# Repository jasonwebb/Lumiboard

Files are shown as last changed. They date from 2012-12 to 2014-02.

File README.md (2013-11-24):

## Lumiboard

Lumiboard is an open-source platform for controlling many types of LEDs. An external sensor board enables tons of fun interactivity, and an on-board Bluetooth transceiver let's you control everything via smartphone or tablet. Lumiboard can control all of these types of LEDs:

* Discrete LEDs
* High-power common-cathode RGB (or single-color) LEDs, up to 5W
* Basic LED strips
* Digitally-addressable LED arrays (such as NeoPixel-based packages)
* I2C LED pixels (like the BlinkM)

## Board features
* **ATMega328** with the Arduino Pro Mini (8 mHz @ 3.3V) bootloader flashed
* **Screw terminals** allow all board functions to be easily tapped into.
* **Six PWM pins** broken out and connected through a ULN2003, so you can sink two high-power RGB LEDs.
* **I2C interface** (SDA and SCL pins) for programmable LEDs like the BlinkM. 
* **Three potentiometer inputs** so you can control RGB colors directly, or connect other sensors as analog inputs.
* **External sensor board** containing a temperature sensor, ambient light sensor and sound sensor.
* **Bluetooth transceiver** accessible via SoftwareSerial, so you can easily control your LEDs remotely using your smartphone or tablet.
* **FTDI interface (3.3V)** so you can re-program the board at any time manually.

## More information
* Author website: http://jason-webb.info
* All my blog posts about this project: http://jason-webb.info/tag/lumiboard/
* Wiki: http://jason-webb.info/wiki/index.php?title=Lumiboard

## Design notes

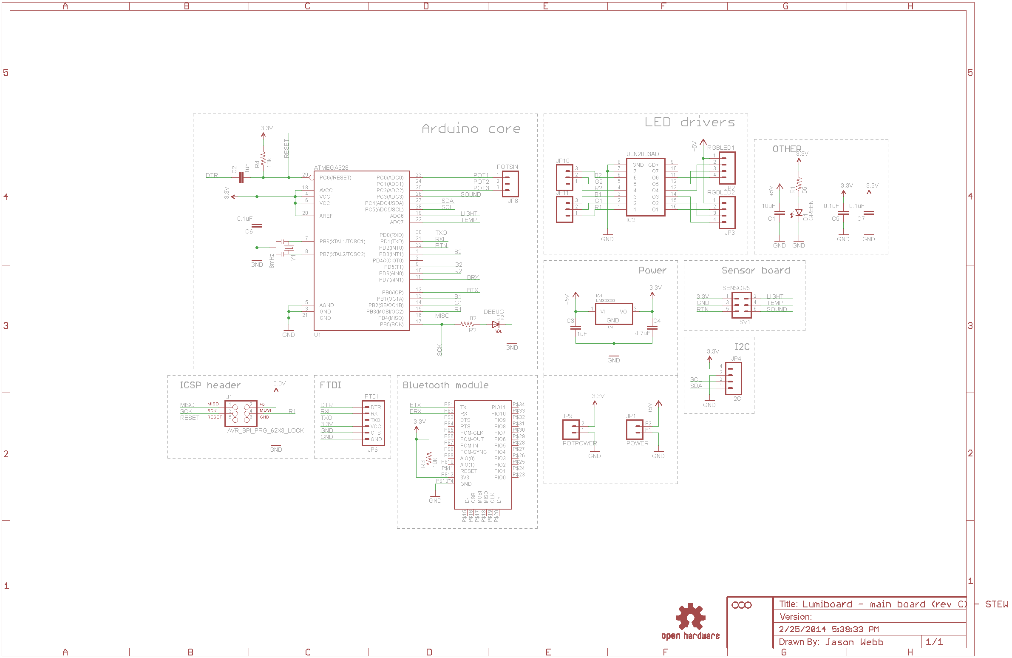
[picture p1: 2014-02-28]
Eagle files/Main board (rev C)/Lumiboard - main board (rev C) schematic.png

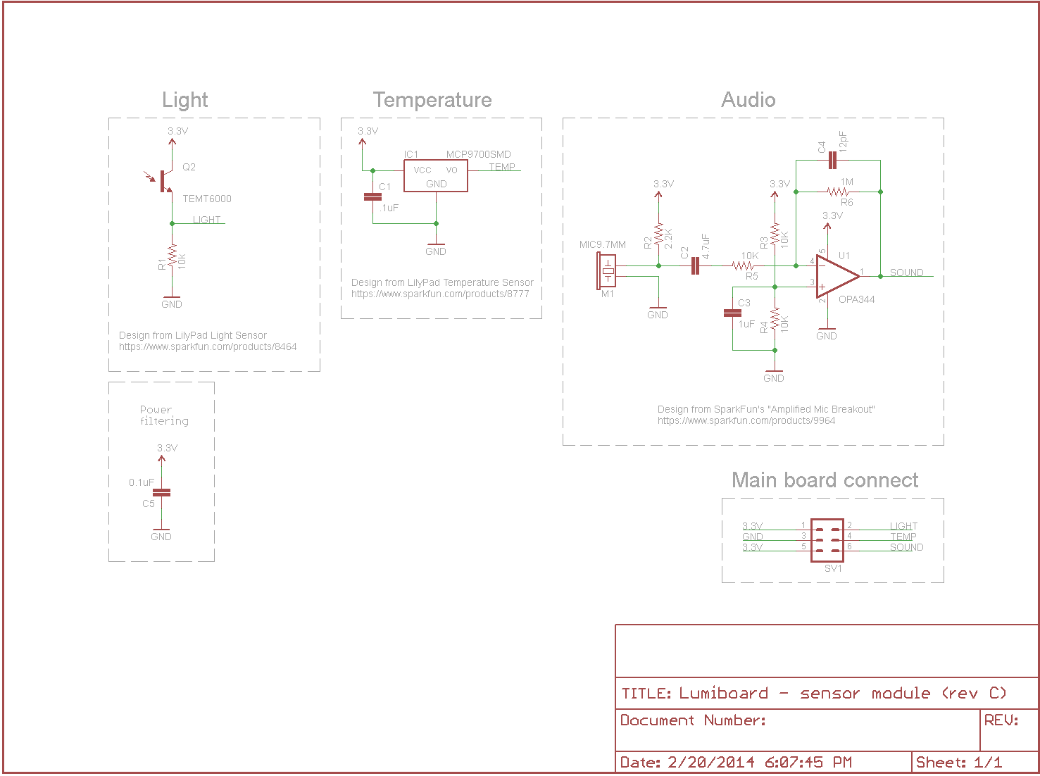
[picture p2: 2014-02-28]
Eagle files/Sensor module (rev C)/Lumiboard - sensor module (rev C) schematic.png

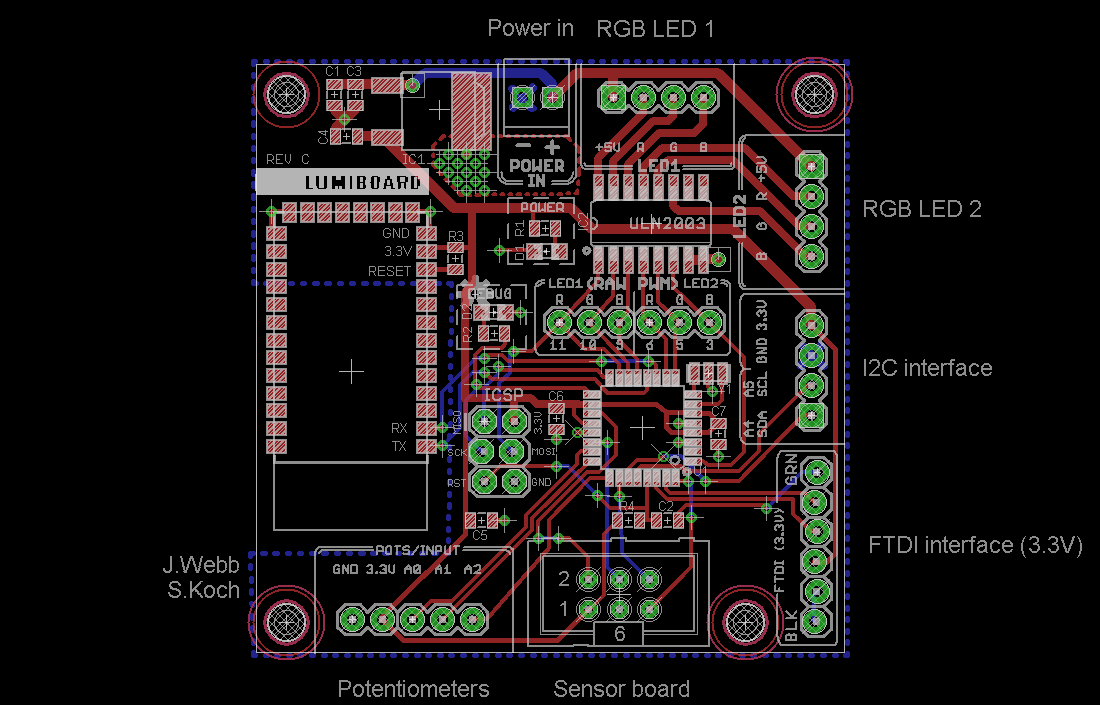
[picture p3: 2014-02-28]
Eagle files/Main board (rev C)/Lumiboard - main board (rev C) PCB.png

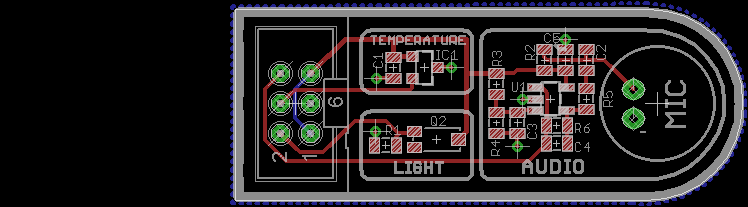
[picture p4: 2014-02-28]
Eagle files/Sensor module (rev C)/Lumiboard - sensor module (rev C) PCB.png

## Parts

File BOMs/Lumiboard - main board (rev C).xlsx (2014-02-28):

ID | Value | Package | Cost | Cost @ 50 | Cost @ 100 | Part number | Source
C1 | 10uF | 0805 | $0.20 | $0.1360 | $0.0693 | 445-7660-1-ND | http://www.digikey.com/product-detail/en/C2012X5R1A106K125AB/445-7660-1-ND/2733732
C2 | 1uF | 0805 | $0.10 | $0.0386 | $0.0327 | 1276-1066-1-ND | http://www.digikey.com/product-detail/en/CL21B105KAFNNNE/1276-1066-1-ND/3889152
C3 | 1uF | 0805 | $0.10 | $0.0386 | $0.0327 | 1276-1066-1-ND | http://www.digikey.com/product-detail/en/CL21B105KAFNNNE/1276-1066-1-ND/3889152
C4 | 4.7uF | 0805 | $0.14 | $0.0552 | $0.0456 | 1276-1065-1-ND | http://www.digikey.com/product-detail/en/CL21A475KOFNNNE/1276-1065-1-ND/3889151
C5 | 0.1uF | 0805 | $0.10 | $0.0240 | $0.0204 | 1276-1099-1-ND | http://www.digikey.com/product-detail/en/CL21B104KACNNNC/1276-1099-1-ND/3889185
C6 | 0.1uF | 0805 | $0.10 | $0.0240 | $0.0204 | 1276-1099-1-ND | http://www.digikey.com/product-detail/en/CL21B104KACNNNC/1276-1099-1-ND/3889185
C7 | 0.1uF | 0805 | $0.10 | $0.0240 | $0.0204 | 1276-1099-1-ND | http://www.digikey.com/product-detail/en/CL21B104KACNNNC/1276-1099-1-ND/3889185
D1 | Power LED (green) | 0805 | $0.08 | $0.0680 | $0.0546 | 475-1410-1-ND | http://www.digikey.com/product-detail/en/LG%20R971-KN-1-0-20-R18/475-1410-1-ND/1802598
D2 | Debug LED (red) | 0805 | $0.41 | $0.2890 | $0.1901 | 160-1579-1-ND | http://www.digikey.com/product-detail/en/LTST-C170TBKT/160-1579-1-ND/564889
IC1 | LM39300 | D-PAK | $1.57 | $1.2528 | $1.0962 | 497-6874-1-ND | http://www.digikey.com/product-detail/en/LD39300DT33-R/497-6874-1-ND/1880253
IC2 | ULN2003AD | 16-SOIC | $0.59 | $0.4332 | $0.3708 | 296-1368-1-ND | http://www.digikey.com/product-detail/en/ULN2003ADR/296-1368-1-ND/404968?cur=USD
J1 | 2x3 ICSP header
JP1 | Main power input | 2-pin .100" pitch terminal block | $0.54 | $0.4080 | $0.3910 | ED10561-ND | http://www.digikey.com/product-detail/en/OSTVN02A150/ED10561-ND/1588862
JP2 | RGB LED 1 output | 4-pin .100" pitch terminal block | $0.99 | $0.7820 | $0.7480 | ED10563-ND | http://www.digikey.com/product-detail/en/OSTVN04A150/ED10563-ND/1588864
Jp3 | RGB LED 2 output | 4-pin .100" pitch terminal block | $0.99 | $0.7820 | $0.7480 | ED10563-ND | http://www.digikey.com/product-detail/en/OSTVN04A150/ED10563-ND/1588864
JP4 | I2C output | 4-pin .100" pitch terminal block | $0.99 | $0.7820 | $0.7480 | ED10563-ND | http://www.digikey.com/product-detail/en/OSTVN04A150/ED10563-ND/1588864
JP6 | FTDI header
JP8 | Pot input | 5-pin .100" pitch terminal block | $1.22 | $0.9660 | $0.9240 | ED10564-ND | http://www.digikey.com/product-search/en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
JP9 | Pot power | (part of above jumper)
JP10 | PWM pins 1 | 1x6 male header | $0.21 | $0.1484 | $0.1378 | 952-2270-ND | http://www.digikey.com/product-detail/en/M20-9990646/952-2270-ND/3728234
JP11 | PWM pins 2 | (part of above jumper)
R1 | 56 ohms | 0805 | $0.10 | $0.0196 | $0.0149 | P56ACT-ND | http://www.digikey.com/product-detail/en/ERJ-6GEYJ560V/P56ACT-ND/42928
R2 | 82 ohms | 0805 | $0.10 | $0.0196 | $0.0149 | P82ACT-ND | http://www.digikey.com/product-detail/en/ERJ-6GEYJ820V/P82ACT-ND/42830
R3 | 10k | 0805 | $0.10 | $0.0196 | $0.0149 | P10KACT-ND | http://www.digikey.com/product-detail/en/ERJ-6GEYJ103V/P10KACT-ND/43118
R4 | 10k | 0805 | $0.10 | $0.0196 | $0.0149 | P10KACT-ND | http://www.digikey.com/product-detail/en/ERJ-6GEYJ103V/P10KACT-ND/43118
SV1 | Sensor connect | 2x3 shrouded header | $0.74 | $0.5542 | $0.5311 | 609-2845-ND | http://www.digikey.com/product-detail/en/75869-131LF/609-2845-ND/1302569?cur=USD
U1 | ATMEGA328P-AU-ND | 32-TQFP | $3.12 | $1.9868 | $1.7738 | ATMEGA328P-AU-ND | http://www.digikey.com/product-detail/en/ATMEGA328P-AU/ATMEGA328P-AU-ND/1832260
U2 | HM-10 BLE4 module | Breakout board | $6.87 | $6.25 | $6.25 | 1292002 | http://www.fasttech.com/product/1292002-ti-cc2540-bluetooth-4-0-ble-2540-transparent
Y1 | 8 mHz resonator | 3-SMD | $0.46 | $0.3456 | $0.3074 | 490-1195-1-ND | http://www.digikey.com/product-detail/en/CSTCE8M00G55-R0/490-1195-1-ND/584632?cur=USD
 |  | Parts total (without BT) | $13.15 | $9.22 | $8.32
 |  | Parts total (with BT) | $20.02 | $15.47 | $14.57

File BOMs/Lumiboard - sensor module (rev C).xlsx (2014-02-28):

ID | Value | Package | Cost | Cost @ 50 | Cost @ 100 | Part number | Source
C1 | 0.1uF | 0805 | $0.10 | $0.0240 | $0.0204 | 1276-1099-1-ND | http://www.digikey.com/product-detail/en/CL21B104KACNNNC/1276-1099-1-ND/3889185
C2 | 4.7uF | 0805 | $0.14 | $0.0552 | $0.0456 | 1276-1065-1-ND | http://www.digikey.com/product-detail/en/CL21A475KOFNNNE/1276-1065-1-ND/3889151
C3 | 1uF | 0805 | $0.10 | $0.0386 | $0.0327 | 1276-1029-1-ND | http://www.digikey.com/product-detail/en/CL21B105KBFNNNE/1276-1029-1-ND/3889115
C4 | 12pF | 0805 | $0.10 | $0.0260 | $0.0220 | 1276-1120-1-ND | http://www.digikey.com/product-detail/en/CL21C120JBANNNC/1276-1120-1-ND/3889206
C5 | 0.1uF | 0805 | $0.10 | $0.0240 | $0.0204 | 1276-1099-1-ND | http://www.digikey.com/product-detail/en/CL21B104KACNNNC/1276-1099-1-ND/3889185
IC1 | MCP9700 | SOT23-3 | $0.30 | $0.2100 | $0.1900 | MCP9700T-E/TTCT-ND | http://www.digikey.com/product-detail/en/MCP9700T-E%2FTT/MCP9700T-E%2FTTCT-ND/1212545
M1 | Electret mic | 9.7mm | $0.96 | $0.7460 | $0.5693 | 102-1721-ND | http://www.digikey.com/product-detail/en/CMA-4544PF-W/102-1721-ND/1869981?cur=USD
Q2 | TEMPT6000 ambient light sensor | 1206 | $1.27 | $1.0052 | $0.9045 | 751-1055-1-ND | http://www.digikey.com/product-detail/en/TEMT6000X01/751-1055-1-ND/1681410?cur=USD
R1 | 10k | 0805 | $0.10 | $0.0196 | $0.0149 | P10KACT-ND | http://www.digikey.com/product-detail/en/ERJ-6GEYJ103V/P10KACT-ND/43118
R2 | 2.2k | 0805 | $0.10 | $0.0196 | $0.0149 | P2.2KACT-ND | http://www.digikey.com/product-detail/en/ERJ-6GEYJ222V/P2.2KACT-ND/93214
R3 | 10k | 0805 | $0.10 | $0.0196 | $0.0149 | P10KACT-ND | http://www.digikey.com/product-detail/en/ERJ-6GEYJ103V/P10KACT-ND/43118
R4 | 10k | 0805 | $0.10 | $0.0196 | $0.0149 | P10KACT-ND | http://www.digikey.com/product-detail/en/ERJ-6GEYJ103V/P10KACT-ND/43118
R5 | 10k | 0805 | $0.10 | $0.0196 | $0.0149 | P10KACT-ND | http://www.digikey.com/product-detail/en/ERJ-6GEYJ103V/P10KACT-ND/43118
R6 | 1M | 0805 | $0.10 | $0.0288 | $0.0219 | P1.00MCCT-ND | http://www.digikey.com/product-detail/en/ERJ-6ENF1004V/P1.00MCCT-ND/119836
SV1 | Main board connect | 2x3 shrouded header | $0.74 | $0.5542 | $0.5311 | 609-2845-ND | http://www.digikey.com/product-detail/en/75869-131LF/609-2845-ND/1302569?cur=USD
U1 | OPA344 | SOT23-5 | $1.66 | $1.3416 | $1.2046 | OPA344NACT-ND | http://www.digikey.com/product-detail/en/OPA344NA%2F250/OPA344NACT-ND/362263
 |  | Unit cost | $6.07 | $4.15 | $3.64

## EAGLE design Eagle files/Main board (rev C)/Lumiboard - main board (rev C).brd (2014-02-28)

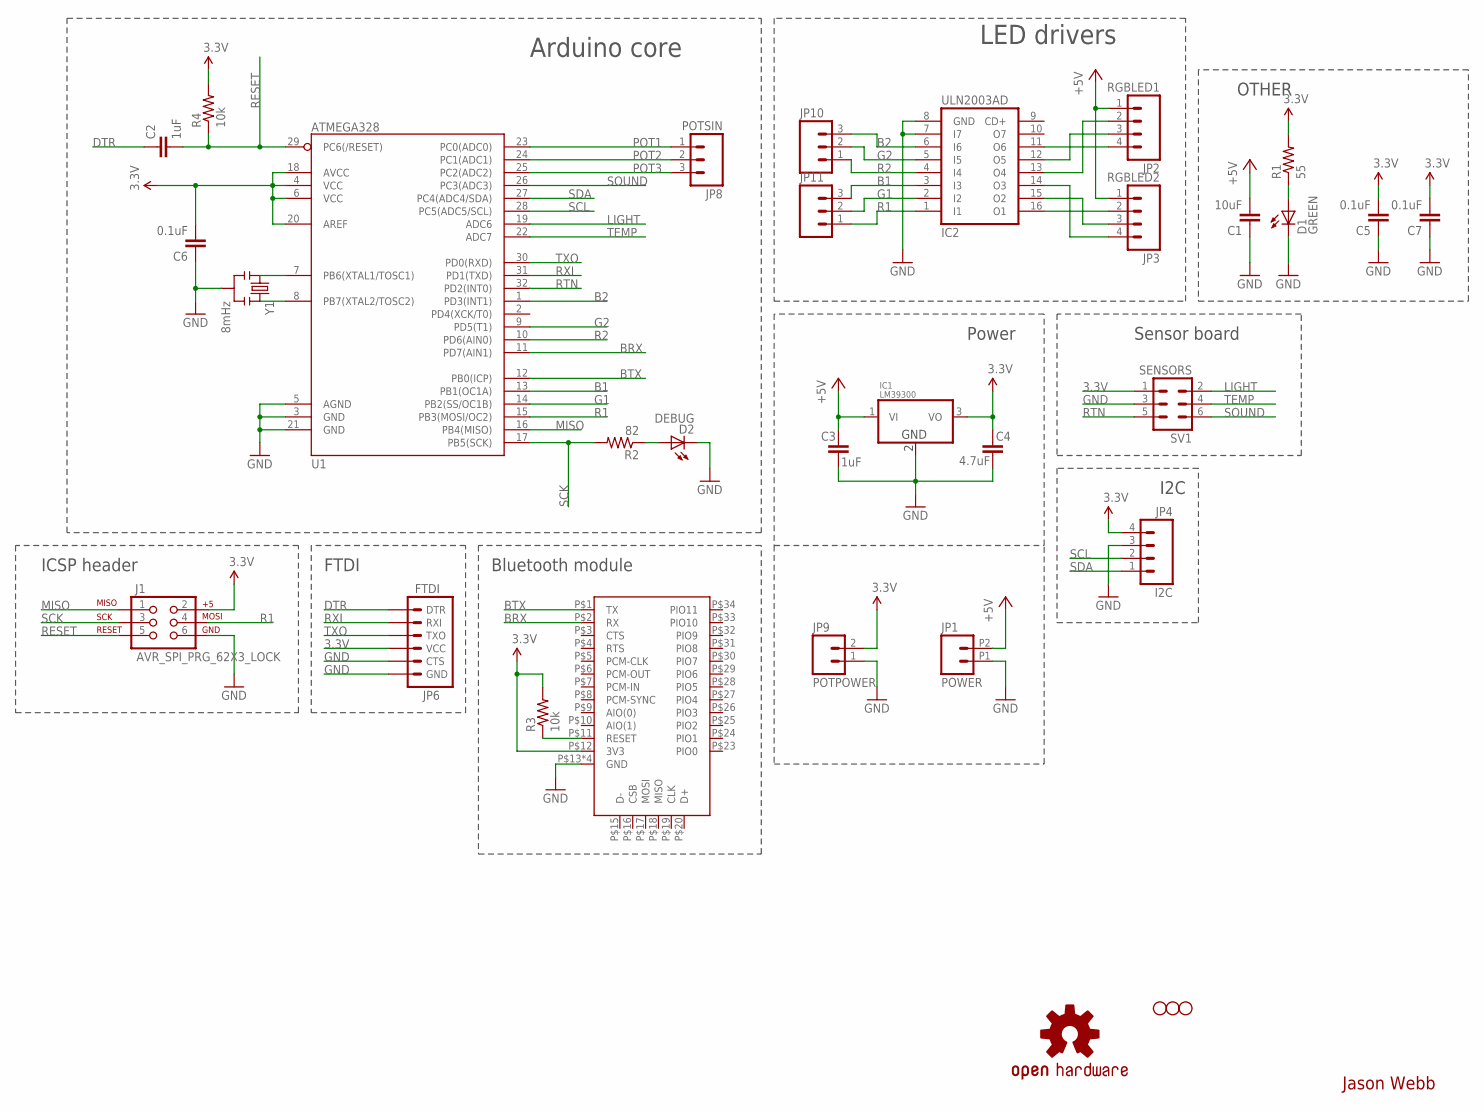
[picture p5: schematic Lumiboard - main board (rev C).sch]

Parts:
C1: 10uF; 0805
C2, C3: 1uF; 0805
C4: 4.7uF; 0805
C5, C6, C7: 0.1uF; 0805
D1: GREEN; CHIPLED_0805
D2: DEBUG; CHIPLED_0805
H1, H2, H3: STAND-OFFTIGHT; STAND-OFF-TIGHT
IC1: LM39300; DPAK
IC2: ULN2003AD; SO16
J1: AVR_SPI_PRG_62X3_LOCK; 2X3_LOCK
JP1: POWER; 1X02_2.54_SCREWTERM
JP2: RGBLED1; 1X04
JP3: RGBLED2; 1X04
JP4: I2C; 1X04
JP6: FTDI; 1X06_LOCK
JP8: POTSIN; 1X03
JP9: POTPOWER; 1X02
JP10, JP11: M03PTH; 1X03
LOGO1: OSHW-LOGOS; OSHW-LOGO-S
R1: 55; 0805
R2: 82; 0805
R3, R4: 10k; 0805
SV1: SENSORS; ML6
U1: ATMEGA328; TQFP32-08
U2: DX_BT_MODULE; DXBLUETOOTHMODULE
Y1: 8mHz; RESONATOR-SMD

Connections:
3.3V: C4.2, C5.2, C6.2, C7.2, IC1.3 (VO), J1.2, JP4.4, JP6.4 (VCC), JP9.2, R1.2, R3.2, R4.2, SV1.1, U1.4 (VCC), U1.6 (VCC), U1.18 (AVCC), U1.20 (AREF), U2.P$12 (3V3)
+5V: C1.2, C3.2, IC1.1 (VI), JP1.P2 (2), JP2.1, JP3.1
B1: IC2.3 (I3), JP11.3, U1.13 (PB1(OC1A))
B2: IC2.6 (I6), JP10.3, U1.1 (PD3(INT1))
BRX: U1.11 (PD7(AIN1)), U2.P$2 (RX)
BTRESET: R3.1, U2.P$11 (RESET)
BTX: U1.12 (PB0(ICP)), U2.P$1 (TX)
DTR: C2.1, JP6.1 (DTR)
G1: IC2.2 (I2), JP11.2, U1.14 (PB2(SS/OC1B))
G2: IC2.5 (I5), JP10.2, U1.9 (PD5(T1))
GND: C1.1, C3.1, C4.1, C5.1, C6.1, C7.1, D1.C, D2.C, IC1.2 (GND), IC2.7 (I7), IC2.8 (GND), J1.6, JP1.P1 (1), JP4.3, JP6.5 (CTS), JP6.6 (GND), JP9.1, SV1.3, U1.3 (GND), U1.5 (AGND), U1.21 (GND), U2.P$13 (GND), U2.P$14 (GND), U2.P$21 (GND), U2.P$22 (GND), Y1.2
LIGHT: SV1.2, U1.19 (ADC6)
MISO: J1.1, U1.16 (PB4(MISO))
unnamed: IC2.16 (O1), JP3.2
unnamed: IC2.15 (O2), JP3.3
unnamed: IC2.13 (O4), JP2.2
unnamed: IC2.14 (O3), JP3.4
unnamed: IC2.12 (O5), JP2.3
unnamed: U1.7 (PB6(XTAL1/TOSC1)), Y1.1
unnamed: U1.8 (PB7(XTAL2/TOSC2)), Y1.3
unnamed: D1.A, R1.1
unnamed: IC2.11 (O6), JP2.4
unnamed: D2.A, R2.1
POT1: JP8.1, U1.23 (PC0(ADC0))
POT2: JP8.2, U1.24 (PC1(ADC1))
POT3: JP8.3, U1.25 (PC2(ADC2))
R1: IC2.1 (I1), J1.4, JP11.1, U1.15 (PB3(MOSI/OC2))
R2: IC2.4 (I4), JP10.1, U1.10 (PD6(AIN0))
RESET: C2.2, J1.5, R4.1, U1.29 (PC6(/RESET))
RTN: SV1.5, U1.32 (PD2(INT0))
RXI: JP6.2 (RXI), U1.31 (PD1(TXD))
SCK: J1.3, R2.2, U1.17 (PB5(SCK))
SCL: JP4.2, U1.28 (PC5(ADC5/SCL))
SDA: JP4.1, U1.27 (PC4(ADC4/SDA))
SOUND: SV1.6, U1.26 (PC3(ADC3))
TEMP: SV1.4, U1.22 (ADC7)
TXO: JP6.3 (TXO), U1.30 (PD0(RXD))

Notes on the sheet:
Jason Webb
Arduino core
Bluetooth module
Sensor board
LED drivers
Power
FTDI
I2C
OTHER
ICSP header

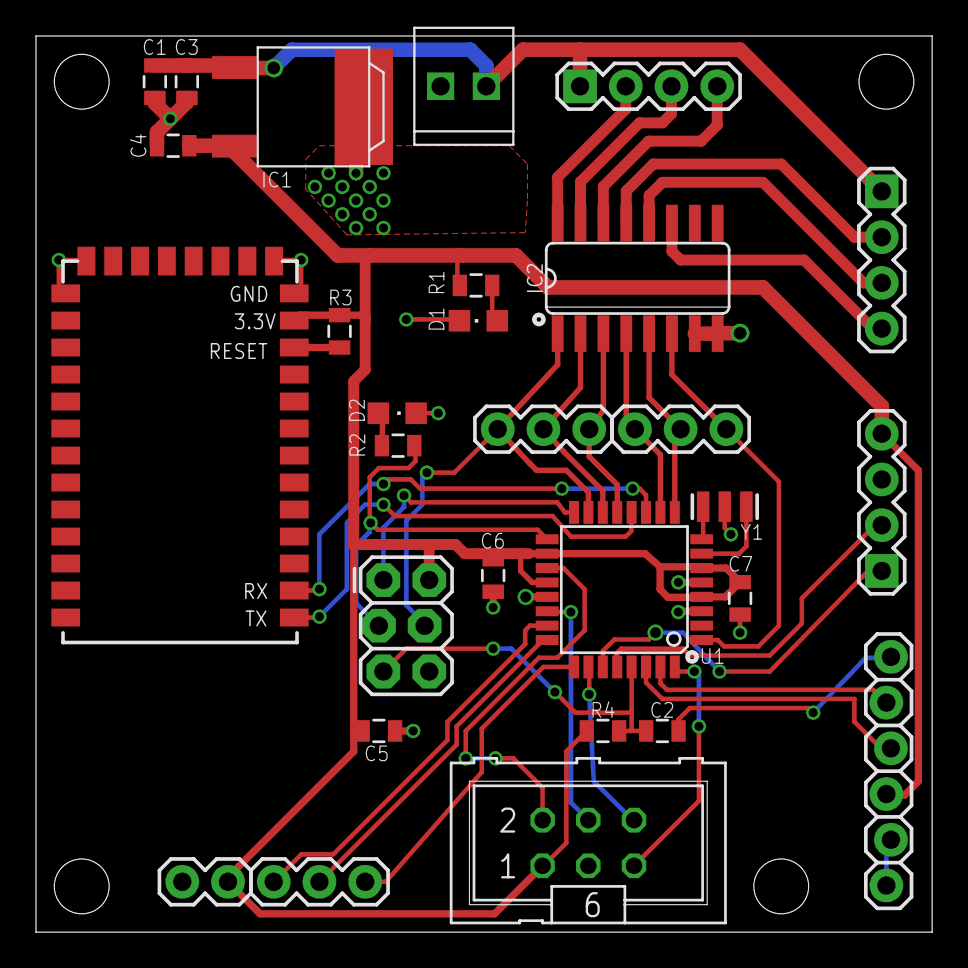
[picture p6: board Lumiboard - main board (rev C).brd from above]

Board: 4 copper layers, 49.8 x 49.8 mm, 34 parts (1 on the bottom side), 37 nets.

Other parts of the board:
H4: STAND-OFFTIGHT; STAND-OFF-TIGHT

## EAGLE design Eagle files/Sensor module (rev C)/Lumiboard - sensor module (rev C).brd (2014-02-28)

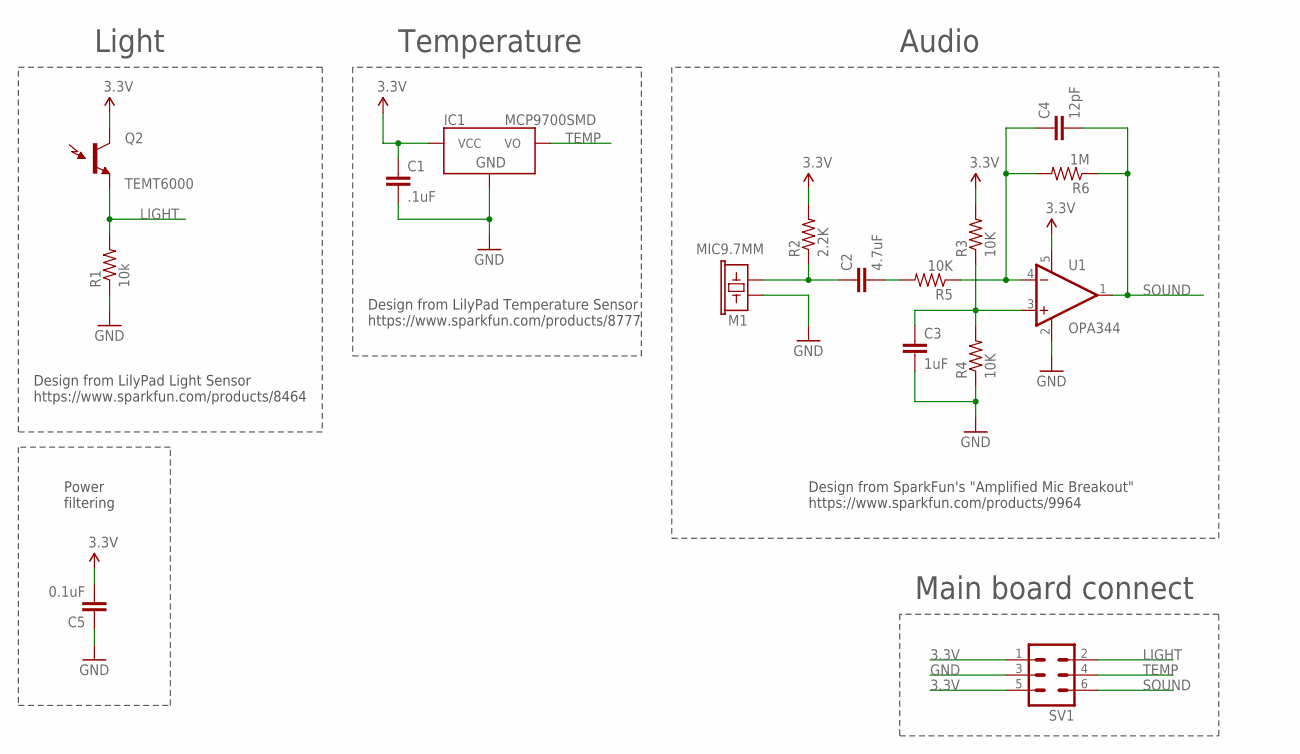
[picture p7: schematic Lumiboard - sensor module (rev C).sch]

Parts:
C1: .1uF; 0805
C2: 4.7uF; 0805
C3: 1uF; 0805
C4: 12pF; 0805
C5: 0.1uF; 0805
IC1: MCP9700SMD; SOT23-3
M1: MIC9.7MM; MIC-9.7MM
Q2: TEMT6000; TEMT6000-SEN
R1: 10k; 0805
R2: 2.2K; 0805
R3, R4, R5: 10K; 0805
R6: 1M; 0805
SV1: ML6
U1: OPA344; SOT23-5

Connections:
3.3V: C1.1, C5.2, IC1.1 (VCC), Q2.COLLECTOR (C1), R2.2, R3.2, SV1.1, SV1.5, U1.5 (V+)
GND: C1.2, C3.2, C5.1, IC1.3 (GND), M1.2, R1.1, R4.1, SV1.3, U1.2 (V-)
LIGHT: Q2.EMITTER (E1), R1.2, SV1.2
unnamed: C2.1, M1.1, R2.1
unnamed: C4.1, R5.1, R6.2, U1.4 (-IN)
unnamed: C2.2, R5.2
unnamed: C3.1, R3.1, R4.2, U1.3 (+IN)
SOUND: C4.2, R6.1, SV1.6, U1.1 (OUT)
TEMP: IC1.2 (VO), SV1.4

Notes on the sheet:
Light
Temperature
Main board connect
Audio
Design from SparkFun's "Amplified Mic Breakout" https://www.sparkfun.com/products/9964
Design from LilyPad Temperature Sensor https://www.sparkfun.com/products/8777
Design from LilyPad Light Sensor https://www.sparkfun.com/products/8464
Power filtering

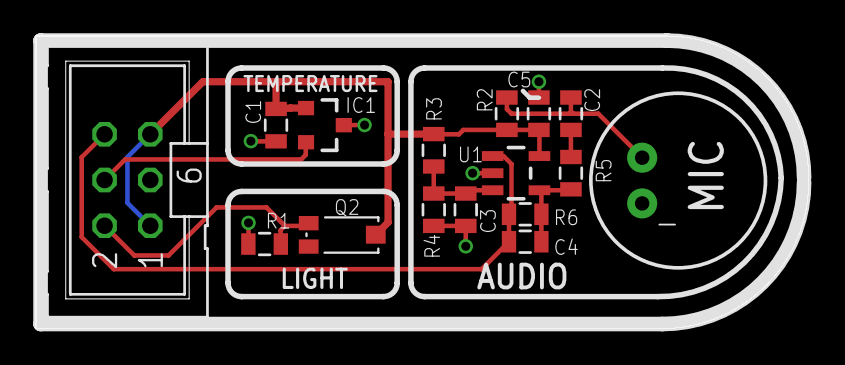
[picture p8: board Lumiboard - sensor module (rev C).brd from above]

Board: 4 copper layers, 42.9 x 16.3 mm, 16 parts (0 on the bottom side), 9 nets.

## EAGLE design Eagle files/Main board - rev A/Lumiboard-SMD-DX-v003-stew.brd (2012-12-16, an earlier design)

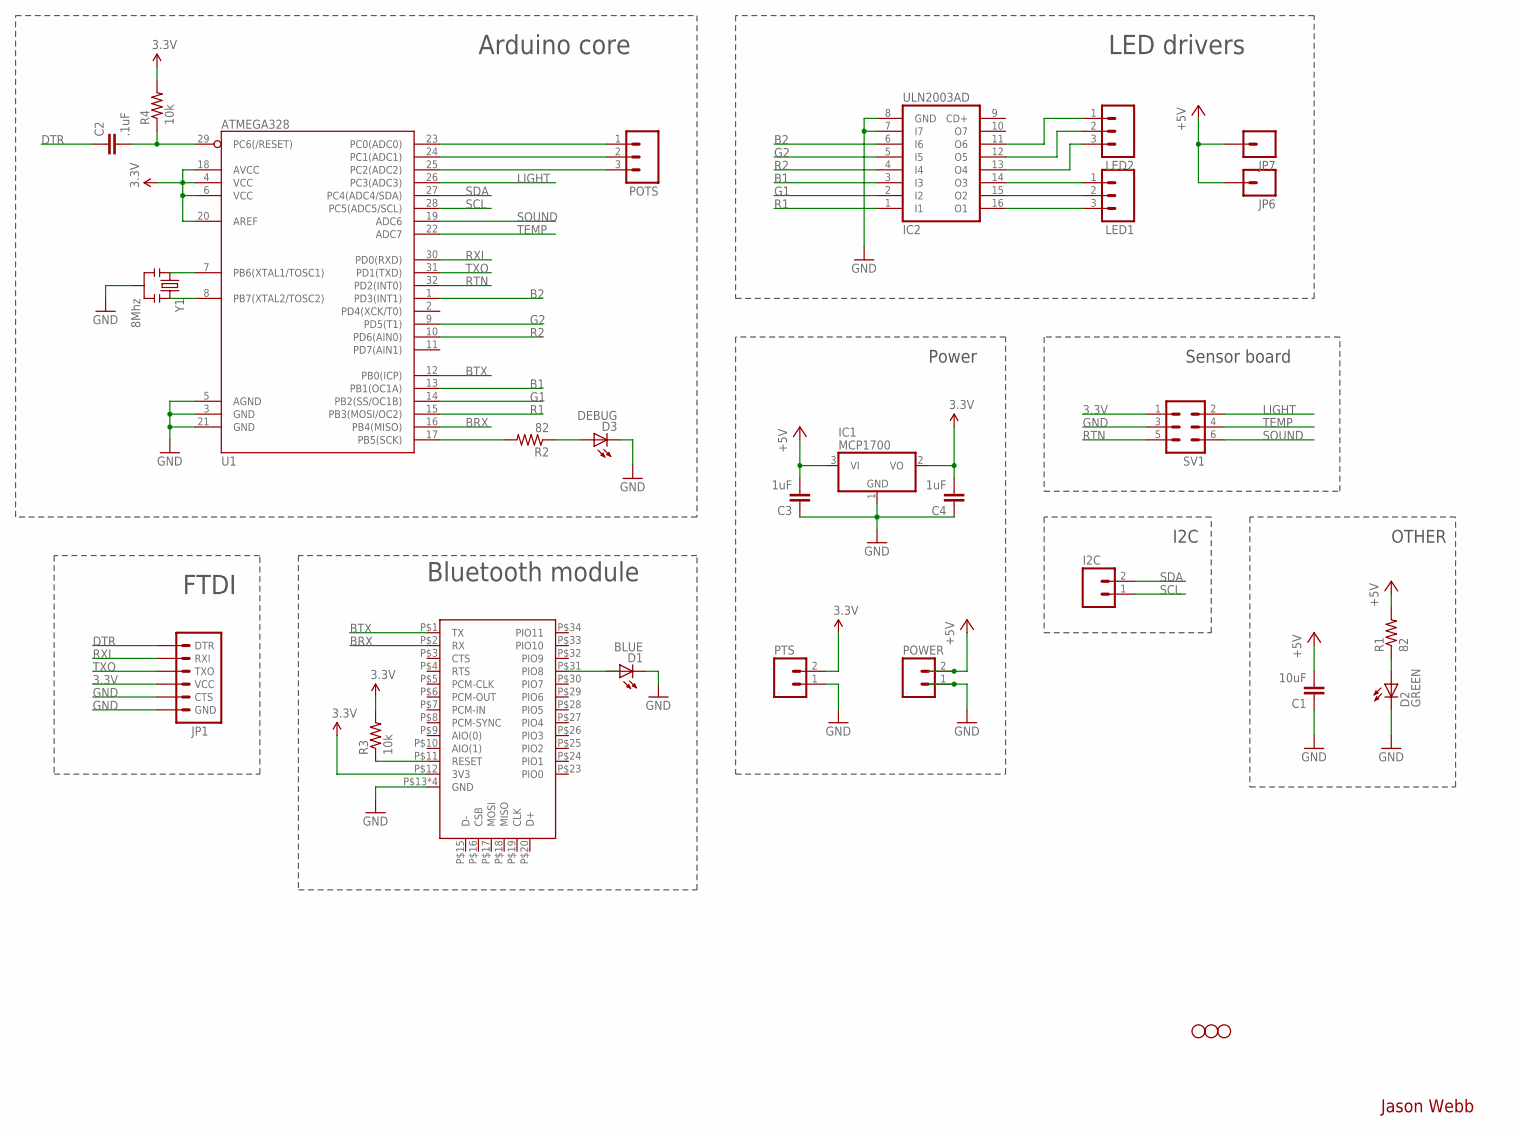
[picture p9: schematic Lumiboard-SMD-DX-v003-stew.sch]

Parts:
C1: 10uF; 0805
C2: .1uF; 0805
C3, C4: 1uF; 0805
D1: BLUE; CHIPLED_0805
D2: GREEN; CHIPLED_0805
D3: DEBUG; CHIPLED_0805
I2C: M02PTH; 1X02
IC1: MCP1700; SOT23
IC2: ULN2003AD; SO16
JP1: ARDUINO_SERIAL_PROGRAMLOCK; 1X06_LOCK
JP2, JP4, JP5: STAND-OFFTIGHT; STAND-OFF-TIGHT
JP6, JP7: M01PTH; 1X01
LED1, LED2: M03PTH; 1X03
POTS: M03PTH; 1X03
POWER: M02PTH; 1X02
PTS: M02PTH; 1X02
R1, R2: 82; R0805
R3, R4: 10k; R0805
SV1: ML6
U1: ATMEGA328; TQFP32-08
U2: DX_BT_MODULE; DXBLUETOOTHMODULE
Y1: 8Mhz; RESONATOR-SMD

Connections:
3.3V: C4.2, IC1.2 (VO), JP1.4 (VCC), PTS.2, R3.2, R4.2, SV1.1, U1.4 (VCC), U1.6 (VCC), U1.18 (AVCC), U1.20 (AREF), U2.P$12 (3V3)
+5V: C1.2, C3.2, IC1.3 (VI), JP6.1, JP7.1, POWER.2, R1.2
B1: IC2.3 (I3), U1.13 (PB1(OC1A))
B2: IC2.6 (I6), U1.1 (PD3(INT1))
BRX: U1.16 (PB4(MISO)), U2.P$2 (RX)
BTX: U1.12 (PB0(ICP)), U2.P$1 (TX)
DTR: C2.1, JP1.1 (DTR)
G1: IC2.2 (I2), U1.14 (PB2(SS/OC1B))
G2: IC2.5 (I5), U1.9 (PD5(T1))
GND: C1.1, C3.1, C4.1, D1.C, D2.C, D3.C, IC1.1 (GND), IC2.7 (I7), IC2.8 (GND), JP1.5 (CTS), JP1.6 (GND), POWER.1, PTS.1, SV1.3, U1.3 (GND), U1.5 (AGND), U1.21 (GND), U2.P$13 (GND), U2.P$14 (GND), U2.P$21 (GND), U2.P$22 (GND), Y1.2
LIGHT: SV1.2, U1.26 (PC3(ADC3))
unnamed: IC2.11 (O6), LED2.1
unnamed: D1.A, U2.P$31 (PIO8)
unnamed: IC2.12 (O5), LED2.2
unnamed: R2.2, U1.17 (PB5(SCK))
unnamed: IC2.13 (O4), LED2.3
unnamed: U1.7 (PB6(XTAL1/TOSC1)), Y1.1
unnamed: U1.8 (PB7(XTAL2/TOSC2)), Y1.3
unnamed: D2.A, R1.1
unnamed: C2.2, R4.1, U1.29 (PC6(/RESET))
unnamed: R3.1, U2.P$11 (RESET)
unnamed: POTS.3, U1.25 (PC2(ADC2))
unnamed: D3.A, R2.1
unnamed: IC2.14 (O3), LED1.1
unnamed: IC2.15 (O2), LED1.2
unnamed: IC2.16 (O1), LED1.3
unnamed: POTS.2, U1.24 (PC1(ADC1))
unnamed: POTS.1, U1.23 (PC0(ADC0))
R1: IC2.1 (I1), U1.15 (PB3(MOSI/OC2))
R2: IC2.4 (I4), U1.10 (PD6(AIN0))
RTN: SV1.5, U1.32 (PD2(INT0))
RXI: JP1.2 (RXI), U1.30 (PD0(RXD))
SCL: I2C.1, U1.28 (PC5(ADC5/SCL))
SDA: I2C.2, U1.27 (PC4(ADC4/SDA))
SOUND: SV1.6, U1.19 (ADC6)
TEMP: SV1.4, U1.22 (ADC7)
TXO: JP1.3 (TXO), U1.31 (PD1(TXD))

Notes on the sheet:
Jason Webb
Arduino core
Bluetooth module
Sensor board
LED drivers
Power
FTDI
I2C
OTHER

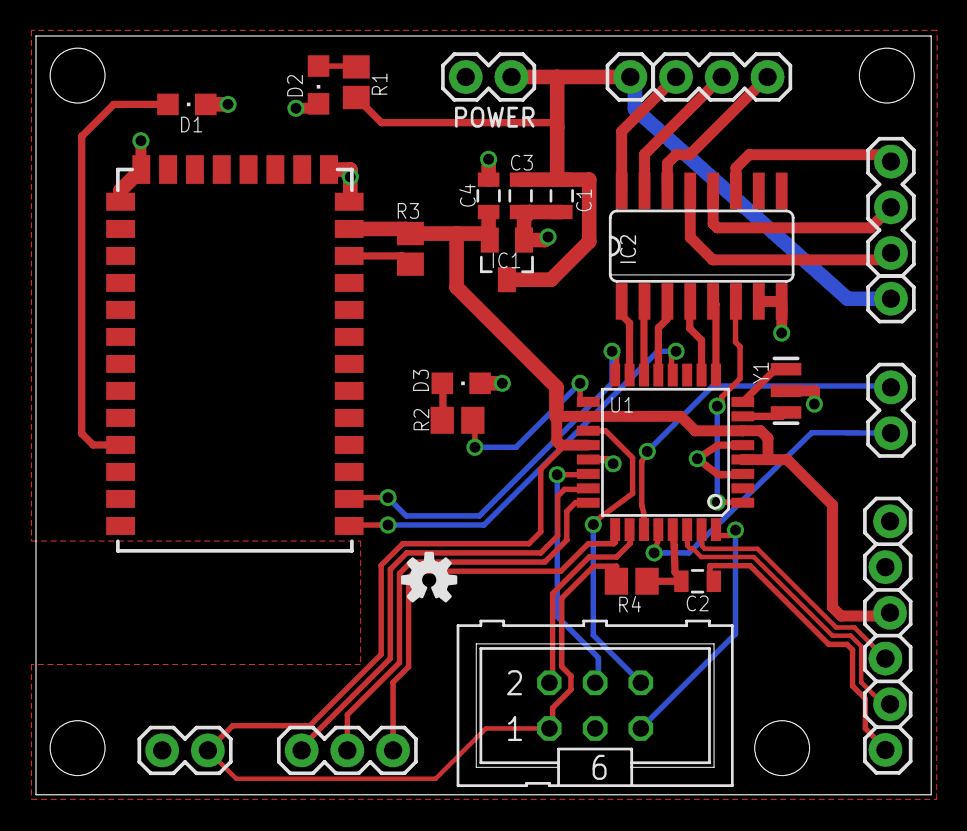
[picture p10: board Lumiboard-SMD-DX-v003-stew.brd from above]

Board: 2 copper layers, 49.7 x 42.2 mm, 31 parts (0 on the bottom side), 37 nets.

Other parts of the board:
JP3: STAND-OFFTIGHT; STAND-OFF-TIGHT
U$1: OSHW-LOGO-S

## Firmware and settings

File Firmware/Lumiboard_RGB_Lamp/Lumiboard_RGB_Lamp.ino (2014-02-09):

/*************************************************************************
 * Lumiboard - RGB LED Lamp
 * 
 * Author: Jason Webb
 * Author website: http://jason-webb.info
 * Author e-mail: zen.webb@gmail.com
 * 
 * Project wiki: http://jason-webb.info/wiki/index.php?title=Lumiboard
 * Github repo: https://github.com/jasonwebb/Lumiboard
 **************************************************************************/
#include <SoftwareSerial.h>

// Pin definitions ======================
#define  LED1_R  11
#define  LED1_G  10
#define  LED1_B  9

#define  LED2_R  6
#define  LED2_G  5
#define  LED2_B  3

#define  DEBUG_LED  13

#define  BT_RX  7
#define  BT_TX  8

#define  POT1  A0
#define  POT2  A1
#define  POT3  A2
#define  POT_THRESHOLD  2

#define  SENSOR_RTN  2
#define  SENSOR_TEMPERATURE  A7
#define  SENSOR_LIGHT  A3
#define  SENSOR_AUDIO  A0  // A6

// Global arrays ===================================================================
float LED1_NEW_RGB[3] = {255,255,0};    // Next values for RGB LED 1 (buffer)
float LED2_NEW_RGB[3] = {255,255,0};    // Next values for RGB LED 2 (buffer)
unsigned int LED1_RGB[3] = {0,0,0};          // Current RGB values of RGB LED 1 (actual values)
unsigned int LED2_RGB[3] = {0,0,0};          // Current RGB values of RGB LED 2 (actual values)
unsigned int current_pot_values[3] = {0,0,0};  // Current RGB potentiometer values
unsigned int new_pot_values[3] = {0,0,0};      // Most recent RGB pot values

// Sensor variables ==========================================================
// Reading buffers
const unsigned int buffer_size = 10;           // Number of readings to take
unsigned int temperature_values[buffer_size];  // Buffer of temperature values
unsigned int light_values[buffer_size];        // Buffer of ambient light values
unsigned int audio_values[buffer_size];        // Buffer of audio values

// Rolling averages
unsigned int averageTemperature = 0;
unsigned int averageLight = 0;
unsigned int averageAudio = 0;

// General operational flags =======================================================
boolean enableLED1 = true;
boolean enableLED2 = true;
boolean enablePots = true;  // Only when pots are connected and you want to use them
boolean enableAudio = false;
boolean debug = true;
boolean sensorDebug = false;

// Specific variables used by various modes ========================================
// GENERAL
float brightness = 1;                // Brightness as a value between 0-1
int fadeSpeed = 10;                  // Milliseconds to wait between each clock cycle. Larger = slower
int counter = 0;                     // General purpose counter
int counterThreshold = 255;          // Tipping point to reset other periodic variables

// COLOR WASH MODE
int decChannel = 0, incChannel = 2;  // Initial channels to wash in "color wash mode"
boolean pickNewColors = true;        // Flag to pick new colors for "color wash mode"
int stepAmount = 1;                  // Amount to step in each cycle of "color wash mode"

// AUDIO REACTIVE MODE
int audioThreshold = 550;            // Minimum value to trigger brightness change

// NIGHTLIGHT MODE
byte nightlightColor[3] = {255,255,255};

// Behavior flow control variables ======================================================
const byte COLOR_WASH_MODE = 0;    // Color washing (blending between all RGB values)
const byte DIRECT_POT_MODE = 1;    // RGB pots directly control LEDs
const byte THERMOMETER_MODE = 2;   // Red = hot, blue = cold
const byte NIGHTLIGHT_MODE = 3;    // Brightness inversely proportional to ambient light
byte INPUT_MODE = DIRECT_POT_MODE;

void setup() {  
  // Take initial reading of pots
  checkPots();

  // Start up Serial connection
  Serial.begin(57600);
}

void loop() {
  switch(INPUT_MODE) {

    // COLOR WASH MODE ================================================
    // Cycle through all RGB values
  case COLOR_WASH_MODE: {
      // Pick new channels to alter once in a while
      if(pickNewColors) {
        incChannel = random(3);

        do {
          decChannel = random(3);
        } while(decChannel == incChannel);

        pickNewColors = 0;
        counter = 0;

        if(debug) {
          Serial.print("PICKING NEW CHANNELS: INC = ");
          Serial.print(incChannel);
          Serial.print(", DEC = ");
          Serial.println(decChannel);
        }
      }

      // Decrement one channel
      if(LED1_RGB[decChannel] > 0) {
        LED1_NEW_RGB[decChannel] -= stepAmount;
        LED2_NEW_RGB[decChannel] -= stepAmount;
      }

      // Increment the other channel      
      if(LED1_RGB[incChannel] < 255) {
        LED1_NEW_RGB[incChannel] += stepAmount;
        LED2_NEW_RGB[incChannel] += stepAmount;
      }

      // Push new colors to LEDs
      //updateLEDs();
      delay(fadeSpeed);

      // Maintain counter, check for overflow
      if(counter >= counterThreshold) {
        pickNewColors = true;
        counter = 0;
      } else {
        counter++;
      }
      
      updateLEDs();

      break; 
    }

    // DIRECT POT MODE ================================================
    // RGB LED values directly controlled by RGB pots
  case DIRECT_POT_MODE: {
      // Check if pots have changed
      boolean potsChanged = checkPots();  

      // If so, update RGB LEDs
      if(potsChanged) {
        for(int i=0; i<3; i++) {
          LED1_NEW_RGB[i] = map(current_pot_values[i], 0, 1023, 0, 255);
          LED2_NEW_RGB[i] = map(current_pot_values[i], 0, 1023, 0, 255);
        }

        updateLEDs();

        // Output debug info via Serial
        if(debug) {
          Serial.print("POTS: ");
          Serial.print(potsChanged);
          Serial.print("\t");

          for(int i=0; i<3; i++) {
            Serial.print(current_pot_values[i]);
            Serial.print("\t");
          }
          Serial.println();
        }
      }        
    } 
    break;

    // THERMOMETER MODE ==============================================
    // Turn red for warm, blue for cool
  case THERMOMETER_MODE: {
      // Check that the sensor board is connected
      boolean sensorsConnected = checkSensors();

      if(sensorsConnected) {   
        float temperature = ((averageTemperature * 5 / 1023) - 0.5) / 0.01;

        if(debug) {
          Serial.print("TEMPERATURE = ");
          Serial.print(temperature);
          Serial.println(" F");
        }
      } else {
        Serial.println("Connect the sensor board!");
      }
    } 
    break;

    // NIGHTLIGHT MODE ====================================================
    // Vary brightness of static color inversely with ambient light
  case NIGHTLIGHT_MODE: {
      // Check that the sensor board is connected
      boolean sensorsConnected = checkSensors();

      if(sensorsConnected) {        
        // DO SOMETHING WITH AVERAGE

        if(debug) {
          Serial.print("AMBIENT LIGHT LEVEL = ");
          Serial.println(averageLight);
        }       
      } else {
        Serial.println("Connect the sensor board!");
      }      
    } 
    break;
  }

  // Audio reactive modulation
  if(enableAudio) {
    // Check sensors if they have not been checked yet
    if(INPUT_MODE == COLOR_WASH_MODE || INPUT_MODE == DIRECT_POT_MODE) {
      boolean sensorsConnected = checkSensors();

      if(sensorsConnected) {
        if(averageAudio >= audioThreshold)
          brightness = .99;
        else
          brightness = 1;

        updateLEDs();
      } else {
        Serial.println("Connect the sensor board!");
      }

      updateLEDs();
    }
  }
}

/*****************************************************
 * Check sensor board for readings
 ******************************************************/
boolean checkSensors() {
  // First make sure the board is connected
  //  byte rtnCheck = digitalRead(SENSOR_RTN);
  byte rtnCheck = 1;

  if(rtnCheck == 0) {
    return false; 
  } else {
    // Shift value buffers down
    for(int i=0; i<buffer_size-1; i++) {
      temperature_values[i] = temperature_values[i+1];
      light_values[i] = light_values[i+1];
      audio_values[i] = audio_values[i+1];
    }

    // Append most recent sensor readings to buffers
    temperature_values[buffer_size-1] = analogRead(SENSOR_TEMPERATURE);  
    light_values[buffer_size-1] = analogRead(SENSOR_LIGHT);
    audio_values[buffer_size-1] = analogRead(SENSOR_AUDIO);

    // Compute new rolling averages for each of the sensors and push to global variables
    int tt = 0, tl = 0, ta = 0;
    for(int i=0; i<buffer_size; i++) {
      tt += temperature_values[i];
      tl += light_values[i];
      ta += audio_values[i];
    }

    averageTemperature = tt/buffer_size;
    averageLight = tl/buffer_size;
    averageAudio = ta/buffer_size;

    if(sensorDebug) {
      Serial.print("TEMP: ");
      Serial.print(averageTemperature);
      Serial.print(", LIGHT: ");
      Serial.print(averageLight);
      Serial.print(", AUDIO: ");
      Serial.println(averageAudio);
    }

    return true;
  }  
}

/*********************************************
 * Check for activity on the RGB pots
 **********************************************/
boolean checkPots() {
  // Get latest readings from pots
  new_pot_values[0] = analogRead(POT1);
  new_pot_values[1] = analogRead(POT2);
  new_pot_values[2] = analogRead(POT3);

  // Update values if they vary significantly
  if((new_pot_values[0] > current_pot_values[0] + POT_THRESHOLD) || (new_pot_values[0] < current_pot_values[0] - POT_THRESHOLD) ||
    (new_pot_values[1] > current_pot_values[1] + POT_THRESHOLD) || (new_pot_values[1] < current_pot_values[1] - POT_THRESHOLD) ||
    (new_pot_values[2] > current_pot_values[2] + POT_THRESHOLD) || (new_pot_values[2] < current_pot_values[2] - POT_THRESHOLD)) {
    for(int i=0; i<3; i++)
      current_pot_values[i] = new_pot_values[i];

    return true;
  } else {
    return false;
  }
}

/***********************************************************************
 * Updates both of the RGB LEDs using the current values of the arrays
 ************************************************************************/
void updateLEDs() {
  updateBrightness();

  // Update LED 1
  if(enableLED1) {
    analogWrite(LED1_R, LED1_RGB[0]);
    analogWrite(LED1_G, LED1_RGB[1]);
    analogWrite(LED1_B, LED1_RGB[2]);
  }

  // Update LED 2
  if(enableLED2) {
    analogWrite(LED2_R, LED2_RGB[0]);
    analogWrite(LED2_G, LED2_RGB[1]);
    analogWrite(LED2_B, LED2_RGB[2]);
  }
}

/**********************************************
 * Updates the brightness of all LEDs
 * - Also pushes RGB buffer to actual values
 **********************************************/
void updateBrightness() {
  // Multiplies brightness scalar across RGB buffers, then pushes result to actual LED values
  for(int i=0; i<3; i++) {
    LED1_RGB[i] = LED1_NEW_RGB[i] * brightness;
    LED2_RGB[i] = LED2_NEW_RGB[i] * brightness;
    Serial.println(LED1_RGB[0]);
  } 
}

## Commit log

2011-12-18 Initial commit of Eagle project files
    [Lampduino-SMD-v001.brd, Lampduino-SMD-v001.sch, Power-Resistor-Breakout-3W-v001.brd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]
2012-12-16 Eagle files, Gerber files, new readme
    [Lumiboard-SMD-DX-v003-stew.brd, Lumiboard-SMD-DX-v003-stew.sch, Power-Resistor-Breakout-3W-v001.brd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]
2012-12-16 Removed old folder
    [Lampduino-SMD-v001.brd, Lampduino-SMD-v001.sch, Power-Resistor-Breakout-3W-v001.brd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]
2013-01-01 New Eagle files
    [Lumiboard - main board (rev B).brd, Lumiboard - main board (rev B).sch, Lumiboard - power resistor board.brd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]
2013-01-01 Added BOMs
    [Lumiboard - LED part guide.xlsx, Lumiboard - hardware BOM.xlsx, Lumiboard - interconnects BOM.xlsx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]
2013-11-24 New BOM, board files and readme
    [Lumiboard - LED part guide.xlsx, Lumiboard - hardware BOM.xlsx, Lumiboard - interconnects BOM.xlsx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]
2014-02-09 Initial firmware and sensor module (rev B)
    [Lumiboard - power resistor board.brd, Lumiboard - power resistor board.sch, Lumiboard - sensor board (rev A).brd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]
2014-02-28 Updated schematics and BOMs
    [Lumiboard - main board (rev B).brd, Lumiboard - main board (rev B).xlsx, Lumiboard - main board (rev C).brd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]

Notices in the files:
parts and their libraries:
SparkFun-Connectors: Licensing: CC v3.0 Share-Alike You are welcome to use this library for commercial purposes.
